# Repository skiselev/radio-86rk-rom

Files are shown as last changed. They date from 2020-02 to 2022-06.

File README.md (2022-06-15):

# Radio 86RK - ROM Cartridge
ROM cartridge for my [Radio-86RK](https://github.com/skiselev/radio-86rk) implementation

## Introduction
This ROM cartridge provides 16 KiB - 32 KiB ROM, that can be used to store the software - development tools, games, and so on.
The ROM cartridge connects to Radio-86RK using the 8255 PPI based parallel interface.

## Using ROM Cartridge

Make sure to power off the computer before connecting the cartridge. Connect the cartridge to the computer using a 26 conductor flat ribbon cable. 

The Radio-86RK ROM monitor provides [**R** command](https://github.com/skiselev/radio-86rk#monitor) that can be used to copy of the ROM cartridge to computer's RAM.
The syntax of **R** command is:
**R\<ROM_Start_Address\>,\<ROM_End_Address\>,\<Destination_Start_Address\>**

The ROM monitor also provides a subroutine to copy ROM cartridge content to the RAM:

* Entry point: 0FA68H
* Input registers:
  * HL - ROM start address
  * DE - ROM end address
  * BC - RAM start address

## Hardware Documentation

### Schematic and PCB Layout

[Schematic - Version 1.1](KiCad/radio-86rk-rom-Schematic-1.1.pdf)

[PCB Layout - Version 1.1](KiCad/radio-86rk-rom-Board-1.1.pdf)

### Connectors and Jumpers

#### J1 - Parallel Port Connector
Pin | Description | Pin | Description
--- | ----------- | --- | ----------------
1   | Output: A8  | 2   | Output: D0
3   | Output: A9  | 4   | Output: D1
5   | Output: A10 | 6   | Output: D2
7   | Output: A11 | 8   | Output: D3
9   | Output: A12 | 10  | Output: D4
11  | Output: A13 | 12  | Output: D5
13  | Output: A14 | 14  | Output: D6
15  | Output: /ROM_CE | 16  | Output: D7
17  | Output: A7 | 18  | Input: A0
19  | Output: A6 | 20  | Input: A1
21  | Output: A5 | 22  | Input: A2
23  | Output: A4 | 24  | Input: A3
25  | Power: +5V  | 26  | Power: GND

#### JP1 and JP2 - ROM Type Configuration

JP1 determines the connection of the ROM's pin 1, while JP2 determines the connection of the ROM's pin 27

ROM Type       | Jumper 1 Position      | Jumper 2 Position
-------------- | ---------------------- | ----------------------------
27C128         | JP1 - 2-3              | JP2 - 1-2 (jumper installed)
27C256, 29C256 | JP1 pin 1 to JP2 pin 1 | JP1 pin 2 to JP2 pin 2
28C256, NVRAM  | JP1 - 1-2              | JP2 - 1-2 (jumper installed)

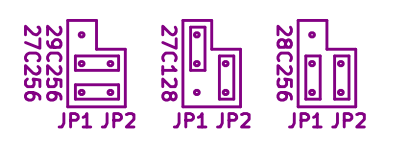
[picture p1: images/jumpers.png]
Radio-86RK ROM Cartridge Jumpers


### Bill of Materials

* [Radio-86RK-ROM project on Mouser.com](https://www.mouser.com/ProjectManager/ProjectDetail.aspx?AccessID=xxxxxxxxxx) - View and order all component except of the PCB.

* [Unicorn Electronics](https://www.unicornelectronics.com/prod.htm) is a good source for UV ERPROMs and EEPROMs

Component type     | Reference | Description                                 | Quantity | Possible sources and notes
------------------ | --------- | ------------------------------------------- | -------- | --------------------------
PCB                |           | Radio-86RK ROM Cartridge PCB - Version 1.1  | 1        | Buy from my Tindie store: [Radio-86RK - PCB](https://www.tindie.com/products/weird/radio-86rk-pcb/) or order from a PCB manufacturer of your choice using provided Gerber or KiCad files
Capacitor          | C1        | 0.1 uF, MLCC, 5 mm Pitch                    | 1        | Mouser [594-K104K15X7RF53H5](https://www.mouser.com/ProductDetail/594-K104K15X7RF53H5)
Connector          | J1        | 13x2 pin header, shrouded                   | 1        | Mouser [517-30326-6002](https://www.mouser.com/ProductDetail/517-30326-6002)
Connector          | JP1       | 3 pin header                                | 1        | Mouser [855-M20-9990345](https://www.mouser.com/ProductDetail/855-M20-9990345)
Connector          | JP2       | 2 pin header                                | 1        | Mouser [855-M20-9990245](https://www.mouser.com/ProductDetail/855-M20-9990245)
Integrated Circuit | U1        | 28C256, 27C256, 27C128                      | 1        | Unicorn Electronics [27C256, 27C128](https://www.unicornelectronics.com/IC/EPROM.html), [28C256](https://www.unicornelectronics.com/IC/EEPROM.html), Mouser [556-AT28C25615PU](https://www.mouser.com/ProductDetail/556-AT28C25615PU)
IC Socket          | U1        | 28 pin DIP                                  | 1        | Mouser [649-DILB28P223TLF](https://www.mouser.com/ProductDetail/649-DILB28P223TLF), [517-4828-6000-CP](https://www.mouser.com/ProductDetail/517-4828-6000-CP)
Connector          | Cable Assembly | 13x2 pin IDC socket                    | 2        | Mouser [517-D89126-0131HK](https://www.mouser.com/ProductDetail/517-D89126-0131HK)
Cable              | Cable Assembly | 26 conductor flat ribbon cable, 1 ft.  | 1        | Mouser [517-3365/26FT](https://www.mouser.com/ProductDetail/517-3365-26FT)

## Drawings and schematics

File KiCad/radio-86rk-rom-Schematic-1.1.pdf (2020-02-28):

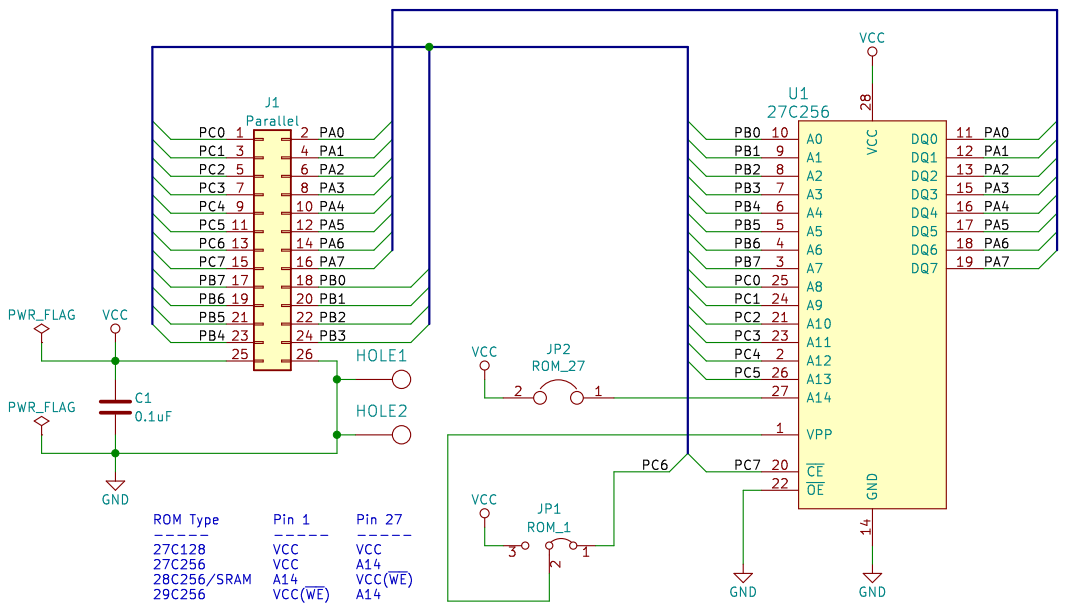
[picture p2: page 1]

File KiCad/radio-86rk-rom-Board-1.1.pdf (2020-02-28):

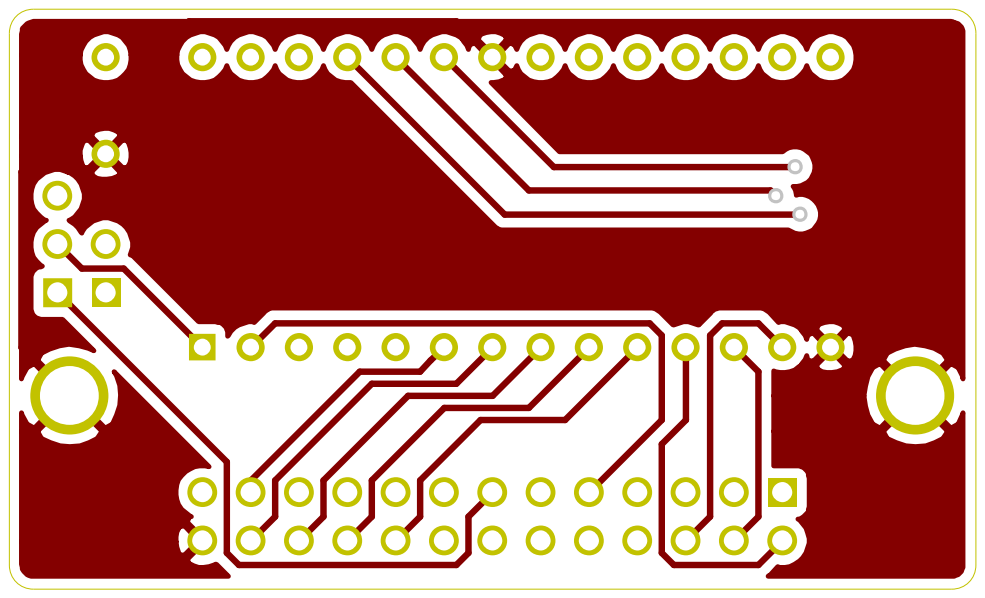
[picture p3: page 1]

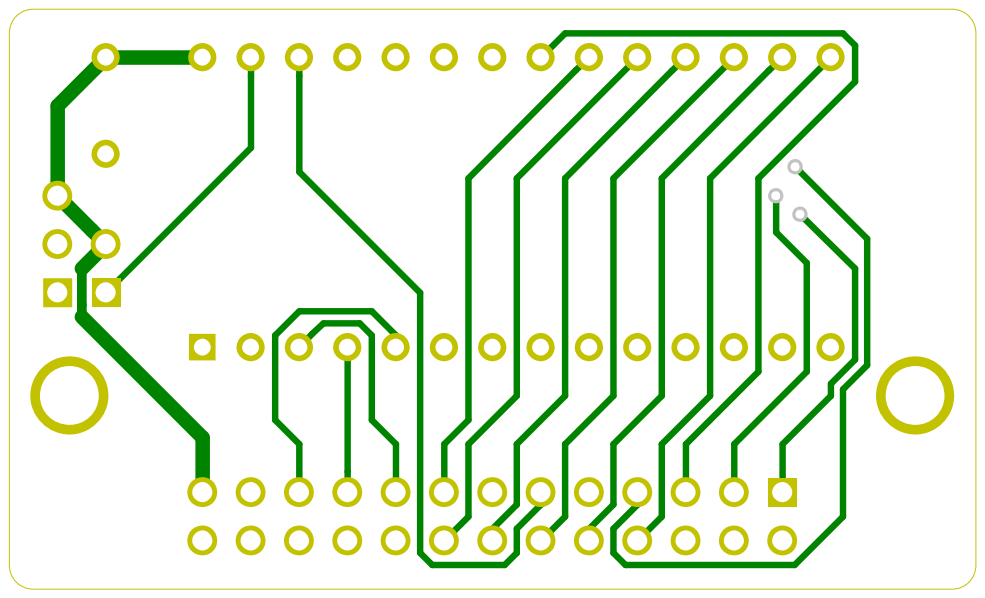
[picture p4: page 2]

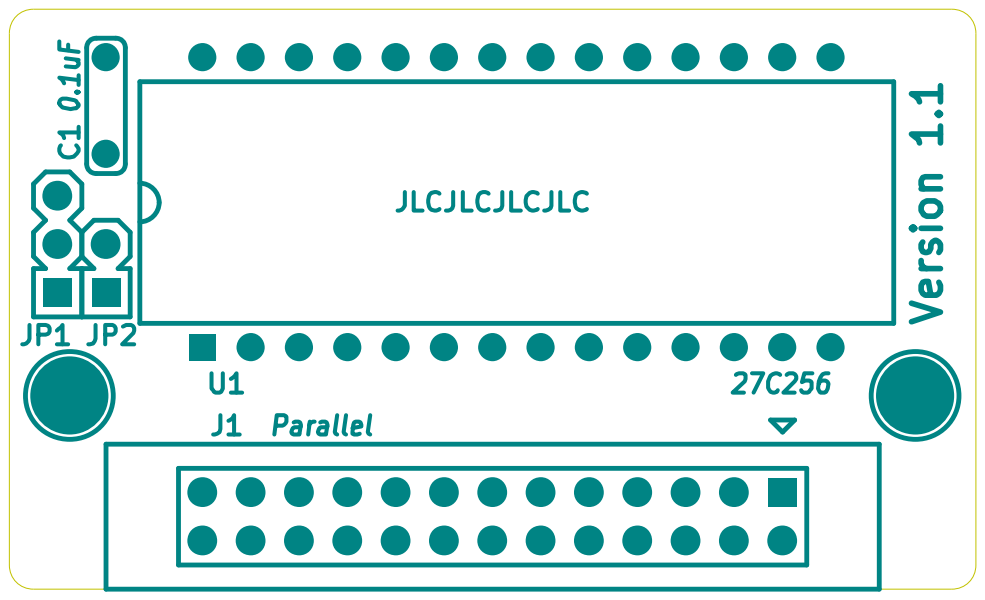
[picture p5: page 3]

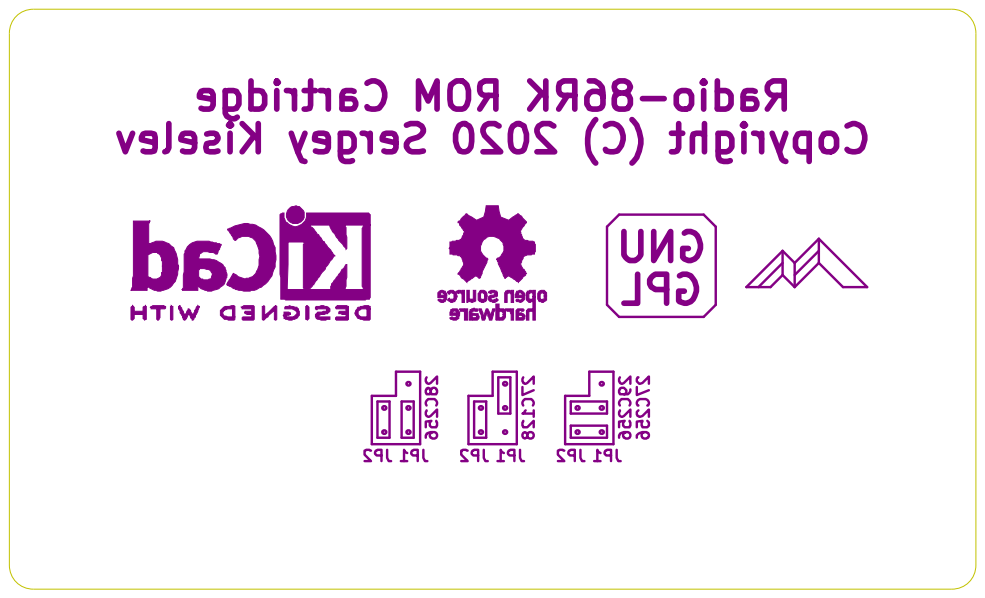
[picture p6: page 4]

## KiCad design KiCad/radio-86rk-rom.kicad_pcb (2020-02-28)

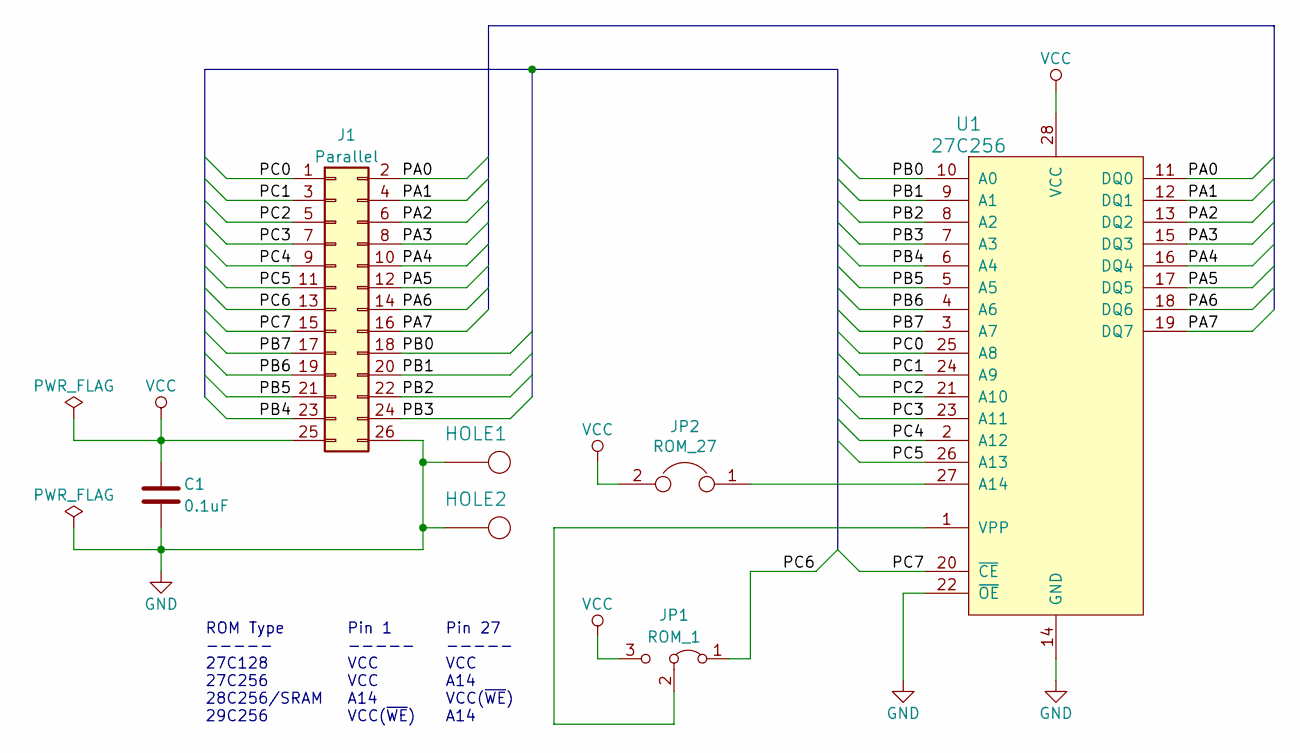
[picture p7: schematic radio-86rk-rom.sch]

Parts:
C1: 0.1uF; Cap_Cer_508
HOLE1, HOLE2: HOLE; Hole_3mm
J1: Parallel; Conn_Pin_Header_13x2_2.54mm_Shrouded
JP1: ROM_1; Conn_Pin_Header_3x1_2.54mm
JP2: ROM_27; Conn_Pin_Header_2x1_2.54mm
U1: 27C256; IC_DIP28_600

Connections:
/PA0: J1.2, U1.11 (DQ0)
/PA1: J1.4, U1.12 (DQ1)
/PA2: J1.6, U1.13 (DQ2)
/PA3: J1.8, U1.15 (DQ3)
/PA4: J1.10, U1.16 (DQ4)
/PA5: J1.12, U1.17 (DQ5)
/PA6: J1.14, U1.18 (DQ6)
/PA7: J1.16, U1.19 (DQ7)
/PB0: J1.18, U1.10 (A0)
/PB1: J1.20, U1.9 (A1)
/PB2: J1.22, U1.8 (A2)
/PB3: J1.24, U1.7 (A3)
/PB4: J1.23, U1.6 (A4)
/PB5: J1.21, U1.5 (A5)
/PB6: J1.19, U1.4 (A6)
/PB7: J1.17, U1.3 (A7)
/PC0: J1.1, U1.25 (A8)
/PC1: J1.3, U1.24 (A9)
/PC2: J1.5, U1.21 (A10)
/PC3: J1.7, U1.23 (A11)
/PC4: J1.9, U1.2 (A12)
/PC5: J1.11, U1.26 (A13)
/PC6: J1.13, JP1.1 (A)
/PC7: J1.15, U1.20 (~CE)
GND: C1.2, HOLE1.1, HOLE2.1, J1.26, U1.14 (GND), U1.22 (~OE)
unnamed: JP1.2 (C), U1.1 (VPP)
unnamed: JP2.1, U1.27 (A14)
VCC: C1.1, J1.25, JP1.3 (B), JP2.2, U1.28 (VCC)

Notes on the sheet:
ROM Type ----- 27C128 27C256 28C256/SRAM 29C256
Pin 1 ----- VCC VCC A14 VCC(~WE~)
Pin 27 ----- VCC A14 VCC(~WE~) A14

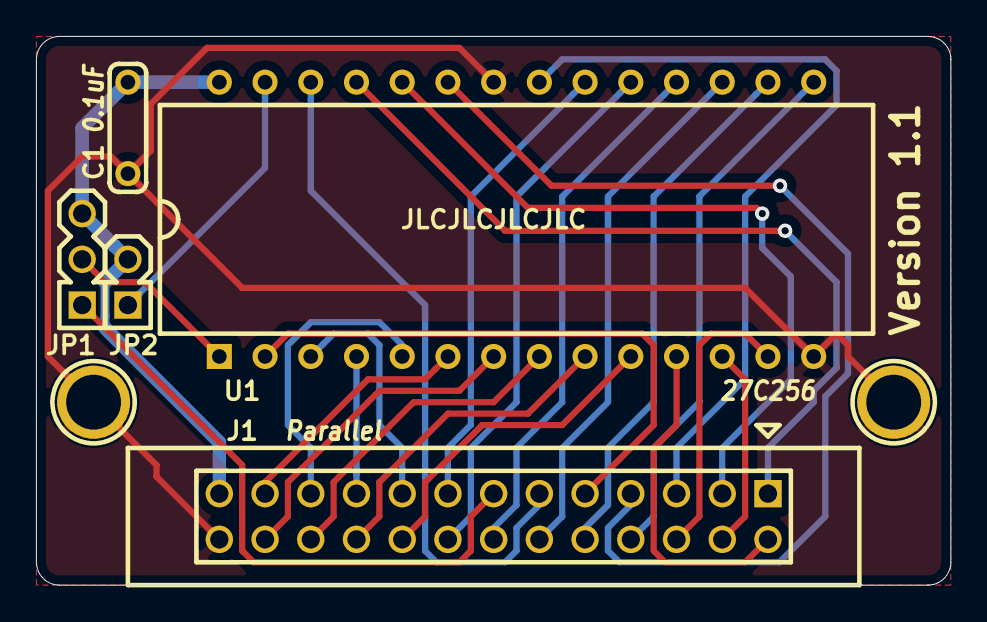
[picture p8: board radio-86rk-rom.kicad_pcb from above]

Board: 2 copper layers, 50.8 x 30.5 mm, 7 parts (0 on the bottom side), 28 nets.

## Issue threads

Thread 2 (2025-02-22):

Add support for М27С801 or 29C040 MultiBank ROM or SD-Card

explit7, 2025-02-22:
Hello @skiselev
I ask me, how complicated it would be to add bigger ROM like 27C801 or 29C040

The discussion (in Russian) is here:
https://zx-pk.ru/threads/12137-radio-86rk-vneshnij-rom-disk.html

There are also many schematics and different solutions. But i don't understand, which would be the best (from your professional point of view). Maybe you can help here and create such schematics ?

While your 32KB Extension ROM is very handy - i would like to create one big ROM (with bank switching) to add all different kinds of programs and games for the RK86.

When you think, that SD-Card would be better solution - maybe go this way?

Also bigger 8KB Monitor which includes DOS is very cool, when you can use it for switching Programs on the ROM.
Started with "U" from Monitor.

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

skiselev, 2025-03-03:
It's a very long thread 😉

### Summary

As I understand, there are at least three designs discussed there:

1. 32 KiB ROM disk - similar to this project, and also similar to what the original Radio 86RK designers had in mind.
2. Larger capacity ROM disk, implemented as multiple 32 KiB banks. The banks are manually selected by the user, using one or two buttons. Some designs use a counter, such as 74LS93 (К555ИЕ5, К155ИЕ5) or 74LS192/74LS193 (К155ИЕ6, К155ИЕ7) to select the page. There is also a design that uses a microcontroller - on the third and the fourth picture above in your question. Supposedly the advantage of using a microcontroller is that the firmware saves the selected bank in the microcontroller's EEPROM, so that the ROM disk keeps the selected bank number across power off and power on cycles.
3. Combination of a ROM disk and a RAM disk, where the bank is software selectable. The second picture above is the schematic for that design ([link to the respective post in the thread](https://zx-pk.ru/threads/12137-radio-86rk-vneshnij-rom-disk.html?p=911460&viewfull=1#post911460)), and the first picture is the screenshot of the operating system (more like a TUI?!) for it. Unfortunately the resolution of the schematic is not very good. From what I can tell it uses a КР1533ИР23 (74LS374) octal D flip-flop to select the memory bank. The memory consist of two 512 KiB SRAM chips, that seem to be battery backed-up, and one 512 KiB Flash ROM IC.

### Discussion

The first and the second options are supported by 'R' directive of the original Radio-86RK ROM monitor
* Note: The original documentation claims that the monitor supports read-only disks up to 32 KiB, as it uses the 8255A PPA (КР580ВВ55А) port A for data, and ports B and C for 15 bit address and the output enable signal. I think we had a discussion and established that it is possible to use 64 KiB ROMs, where all 16 bits of ports B and C are used for address. (Was it ever tested?)

It appears that third option requires an [alternative 8 KiB monitor](https://zx-pk.ru/threads/12137-radio-86rk-vneshnij-rom-disk.html?p=847269&viewfull=1#post847269) and will not work with the original ROM monitor. My concern is that there are no replies from Vladimir_S - the author of the schematic and the ROM monitor / "OS". He also didn't publish the source code. On the positive side **if** the software and the hardware work, it would be much more flexible and easy to use than the original ROM monitor.

I don't have time to assemble and test the second or the third option, but if you do, and you can make it work, I could work on a schematic and PCB for it.

explit7, 2025-03-03:
Thank you for the long explanation, Sergey! If you could make schematics and PCB in KiCad, i would be very happy to assemble it and test!

skiselev, 2025-03-05:
Well, let me know if you need any help with that, I can walk you through KiCad usage.

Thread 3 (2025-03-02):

Help for a newbie

atsip76, 2025-03-02:
Сергей, приветствую!
Подскажите строчу запуска меню из ROM диска для новичка.
Все собрал, все вроде работает, но никогда с РК86 дела не имел.
Просто выполнение R ничего не дает, чистый экран.
Как я понял для обращения к ROM диску нужно указать после R начальный адрес, конечный, и адрес в RAM
Вы не могли бы просто привести нужную строчку для загрузки ROM?

explit7, 2025-03-02:
> Сергей, приветствую! Подскажите строчу запуска меню из ROM диска для новичка. Все собрал, все вроде работает, но никогда с РК86 дела не имел. Просто выполнение R ничего не дает, чистый экран. Как я понял для обращения к ROM диску нужно указать после R начальный адрес, конечный, и адрес в RAM Вы не могли бы просто привести нужную строчку для загрузки ROM?

@atsip76 I will switch to English, so other People can also read it. Let me answer for @skiselev
I am also newbie and built the Radio86-RK for the first time.
The exact command i use to load the External ROM content to the RAM for the @skiselev  32K ROM is:
`R0,200,0
G`

Maybe its possible to do it better, thats the way i found.
There exist another ROM Images like the both in zipped attachment:
I load them with the command:
`R7E00,7FFF,7400
G7400 `

[romdisk.zip](https://github.com/user-attachments/files/19042395/romdisk.zip)

atsip76, 2025-03-02:
Super!
Thank you, ROM loading works, but games freeze the computer when launched :)

explit7, 2025-03-02:
Which ROM exact have you tried? @skiselev ROM with BASIC, Tetris, Xonix  and Otello? I tried it again and they work. I play XONIX all the time :) Have you another EPROM/EEPROM to try another 2?

explit7, 2025-03-22:
@atsip76 Double-Check the Jumper Settings:
Seems, that you set your 27C256 ROM as 27C128.
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

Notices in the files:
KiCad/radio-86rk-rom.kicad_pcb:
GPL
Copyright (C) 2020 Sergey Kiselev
